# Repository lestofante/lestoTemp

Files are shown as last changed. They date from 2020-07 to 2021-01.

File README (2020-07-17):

# lestoTemp 

This project is born to provide a quick and easy way to make a WiFi temperature sensor that can live many monts on a couple of AA battery.  
  
ESP8622-12E is used for v1 since this is what I got home, but later revision may switch to an ESP32.  
  
To simplify the schematics I chose to avoid the usage of any power regulator and use direct ~3v from the battery.    
  
Deep sleep will be used, with poeriodic wake up (current estimate, 10min), a measurement is taken and stored;  
to furter reduce power usage, the transmission will happer only once for day.
  
There will be OTA update support, and server will be minimal and self contained, probably I will use a rasperry, or maybe another ESP with and SD card.

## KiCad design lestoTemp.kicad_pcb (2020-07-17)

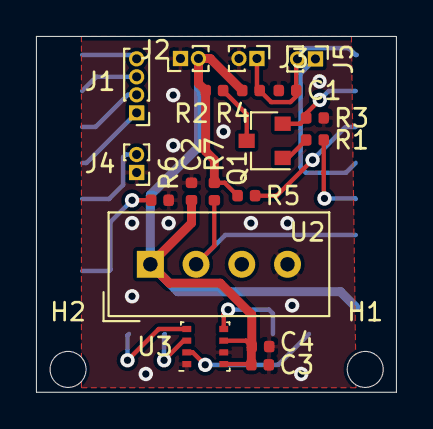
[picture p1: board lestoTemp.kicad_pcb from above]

Board: 2 copper layers, 20.0 x 19.8 mm, 22 parts (1 on the bottom side), 20 nets.

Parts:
C1, C2: 100nF; C_0402_1005Metric
C3, C4: 100nf; C_0402_1005Metric
H1, H2: MountingHole; MountingHole_2mm
J1: PRG; PinHeader_1x04_P1.00mm_Vertical
J2: PWR; PinHeader_1x02_P1.00mm_Vertical
J3: RST; PinHeader_1x02_P1.00mm_Vertical
J4: PRG; PinHeader_1x02_P1.00mm_Vertical
J5: SLP; PinHeader_1x02_P1.00mm_Vertical
Q1: Q_NPN_BCE; SOT-23
R1, R5, R6: 1K; R_0402_1005Metric
R2: 33K; R_0402_1005Metric
R3, R4: 10K; R_0402_1005Metric
R7: 4.7K; R_0402_1005Metric
U1: ESP-12E
U2: DHT11; Aosong_DHT11_5.5x12.0_P2.54mm
U3: BME280; Bosch_LGA-8_2.5x2.5mm_P0.65mm_ClockwisePinNumbering

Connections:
+3V3: C2.1, C3.1, C4.1, J2.2, R2.1, R4.1, R5.1, R7.1, U1.8, U2.1, U3.6, U3.8
ADC: Q1.2, R3.1, U1.2
CLK: U1.14, U3.4
CS: U1.9, U3.2
ENABLE: R5.2, U1.3
GND: C1.2, C2.2, C3.2, C4.2, J2.1, J3.2, J4.1, R3.2, R6.2, U1.15, U2.4, U3.1, U3.7
GPIO0: J4.2, U1.18
GPIO12: R7.2, U1.6, U2.2
GPIO14: R1.1, U1.5
GPIO15: R6.1, U1.16
GPIO16: J5.1, U1.4
unnamed: J1.1, U1.19
unnamed: J1.2, U1.20
unnamed: J1.3, U1.21
unnamed: J1.4, U1.22
unnamed: Q1.1, R1.2
unnamed: Q1.3, R2.2
RESET: C1.1, J3.1, J5.2, R4.2, U1.1
SDI: U1.10, U3.5
SDO: U1.13, U3.3

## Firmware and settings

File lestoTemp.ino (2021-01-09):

#ifdef ESP32
  #include <WiFi.h>
#else
  #include <ESP8266WiFi.h>
#endif

#include <ESPmDNS.h>
#include <WiFiUdp.h>
#include <ArduinoOTA.h>

////// USER CONFIGURATION
#define USE_DHT
//#define USE_BMP // lestoTemp V1.0 WILL NOT WORK, SPI IS CONNECTED WRONG

constexpr char* ssid = "XXXX";
constexpr char* password = "XXXX";
constexpr char* host = "XXX.XXX.XXX.XXX";
constexpr int port = 4444;

constexpr uint64_t SecondsPerReading = 60; //1 read every 60 seconds
constexpr uint32_t ReadingPerTransmission = 60; //60 reading before transmission; with SecondsPerReading = 60 means transmit every hour
constexpr uint32_t ReadingBufferMultiplier = 3; // how many times the buffer has to be bigger. This is basically the number of consecutive failed upload before loosing data
constexpr uint32_t TimeoutConnectionMs = 5000;
////// END USER CONFIGURATION

constexpr uint32_t uS_TO_S_FACTOR = 1000000;

constexpr uint8_t R2 = 33;
constexpr uint8_t R3 = 10;
constexpr uint8_t VoltageDividerMultiplier = R3 / (R2 + R3);

static_assert(VoltageDividerMultiplier * 3.7f < 1.0f, "warning, safe voltage overshoot the ADC");


constexpr uint32_t READING_BUFFER_SIZE = ReadingPerTransmission * ReadingBufferMultiplier;
RTC_DATA_ATTR struct Reading{
  uint32_t timestamp_seconds;
  float temperature;
  float humidity;
  float pressure;
}bufferReadings[READING_BUFFER_SIZE];

#ifdef USE_BMP
  #include "bmp.h"
#endif

#ifdef USE_DHT
  #include "dht.h"
#endif

static_assert(SENSOR_SELECTED==1, "you must select a chip to use");


void deep_sleep_timed(bool enableWifiNextBoot){
#ifdef ESP32
  esp_deep_sleep_start();
#else
  pinMode(16, WAKEUP_PULLUP);
  ESP.deepSleep(SecondsPerReading * 1000 * 1000, enableWifiNextBoot ? WAKE_RF_DEFAULT : WAKE_RF_DISABLED);
#endif
}

uint16_t readBatteryRaw(){

  //enable GPIO and MOSFET
  pinMode(14, OUTPUT);
  digitalWrite(14, HIGH);
  
  //make 2 read to flush the adc HW
  analogRead(A0); // max input range 0-1v

  uint16_t raw_voltage = analogRead(A0);

  //disable the MOSFET and GPIO
  digitalWrite(14, LOW);
  pinMode(14, INPUT);
  
  return raw_voltage;
}

bool transmit_readings(uint8_t numbers){

  bool transmitted = false;
  
  WiFi.mode(WIFI_STA);
  WiFi.begin(ssid, password);
  const uint32_t connection_start = millis();
  
  while (WiFi.status() != WL_CONNECTED && (millis() - connection_start < TimeoutConnectionMs)) {
    delay(1);
  }

  if (WiFi.status() == WL_CONNECTED) {
    WiFiClient tcpClient;
    tcpClient.setTimeout(TimeoutConnectionMs);
    
    if (tcpClient.connect(host, port)) {
      const float battery = 0;//(readBatteryRaw() * VoltageDividerMultiplier) / 1024.0f;
      tcpClient.write(reinterpret_cast<const uint8_t*>(&battery), sizeof(battery));
    
      tcpClient.write(reinterpret_cast<const uint8_t*>(bufferReadings), sizeof(struct Reading) * numbers);

      transmitted = true;
    }
  }
  
  WiFi.disconnect();

  return transmitted;
}

void setup() {
  Serial.begin(115200);

  // Wait for serial to initialize.
  while(!Serial) { }

  Serial.println("STARTED");

#ifdef ESP32
  /*
  First we configure the wake up source
  We set our ESP32 to wake up every 5 seconds
  */
  esp_sleep_enable_timer_wakeup(SecondsPerReading * uS_TO_S_FACTOR);
#endif
}

void loop() {
  RTC_DATA_ATTR static uint32_t counter {0};
  
  //make a read
  Reading r = read_sensor();
  bufferReadings[counter % READING_BUFFER_SIZE] = r;
  Serial.print("readed: ");
  Serial.print(r.temperature);
  Serial.print(" ");
  Serial.println(r.humidity);
  
  counter++;

  if ( (counter % READING_BUFFER_SIZE) == 0){
    // time to transmit thereading and reset the loop counter
    Serial.println("sending data");
    if ( transmit_readings(counter) )
      counter = 0; //reset the counter only if sucessful
  }

  bool enableWifiNextBoot = (counter + 1 >= ReadingPerTransmission);
  //deep_sleep_timed(enableWifiNextBoot);
  delay(2000);
} 

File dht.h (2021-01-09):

#define SENSOR_SELECTED 1
//#include <DHT.h>

constexpr int DHT_PIN = 12; //GPIO12

//DHT dht(DHT_PIN, DHT11);

constexpr uint32_t ISR_ELEMENTS = 85;

struct {
  volatile uint32_t index;
  volatile uint32_t timigs[ISR_ELEMENTS];
} isr_data = {0};


void IRAM_ATTR ICACHE_RAM_ATTR read_dht(){
  if (isr_data.index < ISR_ELEMENTS) {
    isr_data.timigs[isr_data.index++] = micros();
  }
}

Reading read_sensor(){
  pinMode(DHT_PIN, OUTPUT);
  digitalWrite(DHT_PIN, HIGH);
  delay(1);
  
  // First set data line low for a period according to sensor type
  digitalWrite(DHT_PIN, LOW);
  delay(20); // data sheet says at least 18ms, 20ms just to be safe
  
  // End the start signal by setting data line high for 40 microseconds.
  pinMode(DHT_PIN, INPUT_PULLUP);

  attachInterrupt(digitalPinToInterrupt(DHT_PIN), read_dht, CHANGE);
  isr_data.index = 0;
  
  // Delay a moment to let sensor pull data line low.
  delayMicroseconds(10);
  
  // 3ms is the normal read time
  delay(4);

  if (isr_data.index != 84){
    return {millis() / 1000,0,0};
  }

  uint8_t data[5] = {0,0,0,0,0};
  uint8_t offset = 0;
  uint8_t shift = 7;
  for (uint32_t i = 4; i < isr_data.index; i+=2){
    bool bit = (isr_data.timigs[i] - isr_data.timigs[i-1]) > 50;
    data[offset] |= bit << shift;
    shift--;
    if (shift > 7){
      shift = 7;
      offset++;
    }
  }

  if (data[4] == ((data[0] + data[1] + data[2] + data[3]) & 0xFF)) {
    return {millis() / 1000, data[2], data[0], 0};
  }
  
  return {millis() / 1000, 0,0,0};
}

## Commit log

2020-08-02 added missing AP connection, and some other stuff
    [lestoTemp.ino]
2021-01-09 Updated to work on esp32
    broken esp8266
    [lestoTemp.ino]
